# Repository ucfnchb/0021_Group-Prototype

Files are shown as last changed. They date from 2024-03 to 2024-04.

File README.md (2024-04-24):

# Coastal Echoes 
## Introduction
Coastal Echoes is an innovative project combining real-time environmental data with interactive visualization techniques to present dynamic coastal scenes. It utilizes real-time tidal and wind data to animate coastal landscapes visually, allowing the physical reproduction of natural phenomena such as wave motion and beach coverage. This project serves as both a functional tool for marine enthusiasts and an artistic decoration.


## Project Goals
The main objective of Coastal Echoes is to integrate real-time environmental data with Internet of Things technology to generate dynamic representations of coastal environments, helping target users such as shell collectors, surfers, and beachgoers understand and visualize tidal and wind impacts in real-time.



## Product Video: https://www.youtube.com/watch?v=u9kxgSY_1j8
For more Information please see uploaded Powerpoint Presentations.
## Features
* Real-Time Data Visualization: Using tide and wind data to illustrate their effects on wave motion and beach coverage.
* Physical Prototype: Features a motorized mechanism that simulates ocean wave movements correlated with real-time wind speed data.
* LED Visualization: An LED strip displays tide levels with color gradients, enhancing visual feedback.
* User-Friendly Interface: Designed to be intuitive and accessible for all user types.
## Getting Started
### Prerequisites
* Before starting with the installation of the Coastal Echoes project, ensure that you have the following:
* Access to the internet and a suitable environment to run Python scripts (e.g., Google Colab, Jupyter Notebook, or a local Python environment).
* Two APIs for real-time environmental data:
* Wind speed API
* Tide value API
* MQTT broker setup to publish and subscribe to topics.
* Arduino IDE installed on your computer for programming the Arduino Uno WiFi Rev2.
* The following libraries installed in your Arduino IDE:
* MQTT for handling MQTT connections.
* Servo to control the servo motors.
* WiFiNINA for network connectivity on Arduino.
* A Prusa 3D printer or access to one for printing the required parts.
* The 3D model source files for printing parts, available in the GitHub repository.
## Installation
### Software Setup
1.Clone the repository to your local machine or development environment:
```bash
git clone https://github.com/ucfnchb/0021_Group-Prototype.git
```
2.Navigate to the cloned directory and locate the Python scripts for retrieving data from the environmental APIs. These scripts are designed to publish data to MQTT topics. Run these scripts in your chosen environment (local or cloud-based).<br>
3.Locate the Arduino Code folder in the repository, which contains the scripts for the Arduino. You will upload these scripts to the Arduino board in later steps.
### Hardware Assembly

1.Print the required 3D parts using the model source files provided in the repository's 3D_Models folder.Laser cut from the wave dxf file<br>
2.Assemble the hardware according to the assembly diagrams and instructions found in the Diagrams folder. This includes fitting together the 3D-printed parts and the electronic components.<br>
3.Install the LED strips, servo motors, and the Arduino Uno WiFi Rev2 on the assembled hardware.



4. Material for enclosure provided below: 3mm Acrylic board, clear Acetate sheets, Florescent Paint.



### Arduino Configuration
1.Open the Arduino IDE and install the necessary libraries (MQTT, Servo, and WiFiNINA) via the Library Manager. <br>
2.Open the Arduino scripts provided in the Arduino Code folder. <br>
3.Configure the scripts with the correct MQTT topics that the Python scripts are publishing to.<br>
https://github.com/ucfnchb/0021_Group-Prototype/tree/main/API<br>
4.Upload the scripts to your Arduino board, ensuring that it's connected to your computer via USB.<br>
https://github.com/ucfnchb/0021_Group-Prototype/tree/main/Arduino%20Code<br>
5.Connect the Arduino to the local Wi-Fi network as instructed in the script comments.<br>
6.Once the setup is complete, the Arduino board should start receiving data from MQTT and controlling the LED strips and servo motors accordingly, reflecting the real-time environmental data in the physical prototype.
### Usage
* USB Power
* Connect the device to a WiFi network.
* The device will automatically start receiving data and simulating the environmental conditions of the NewHeaven coast.
## Prototype Design
The design process involved meticulous planning and execution, focusing on creating a responsive visualization that is both accurate and pleasing to the eye. For detailed design descriptions, Please see attached DesignDocs. 
## Future Work
Future enhancements will focus on integrating predictive features to forecast unfavorable tidal and wind conditions. We are also exploring options to enhance the device's durability and functionality over prolonged use.
## Contact
Project manager: Stella Chen yanjun.chen.23@ucl.ac.uk

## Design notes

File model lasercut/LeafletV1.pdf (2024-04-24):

# Coastal Echoes

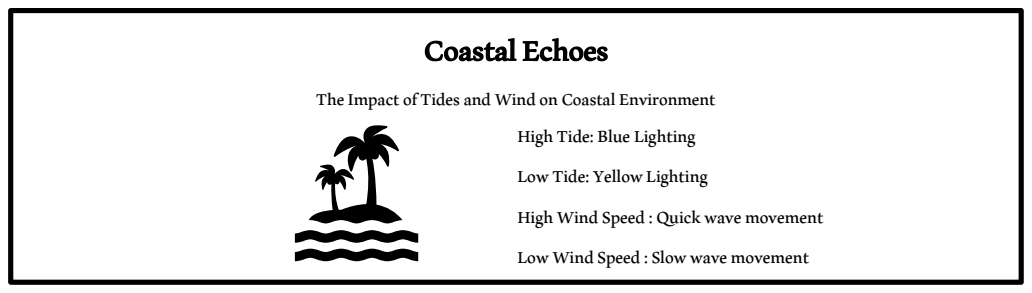
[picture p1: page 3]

The Impact of Tides and Wind on Coastal Environment

High Tide: Blue Lighting
Low Tide: Yellow Lighting
High Wind Speed : Quick wave movement
Low Wind Speed : Slow wave movement

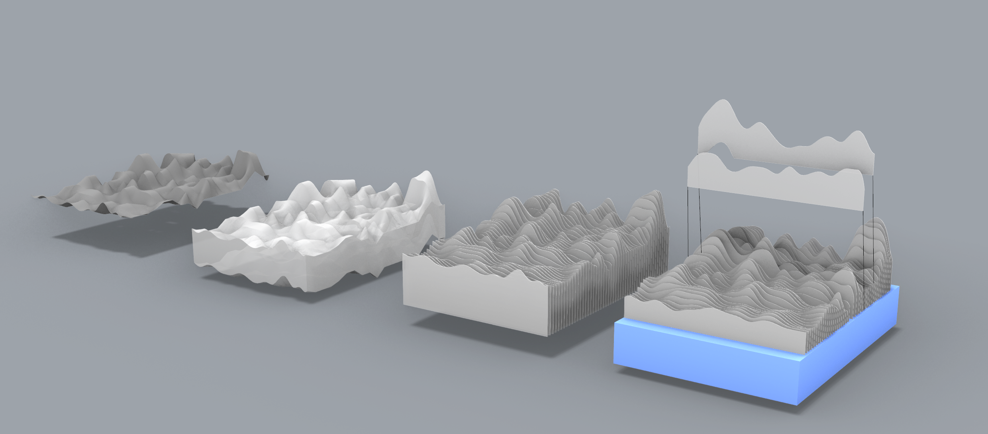
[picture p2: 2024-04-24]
model lasercut/model Image/屏幕截图 2024-03-17 190605.png

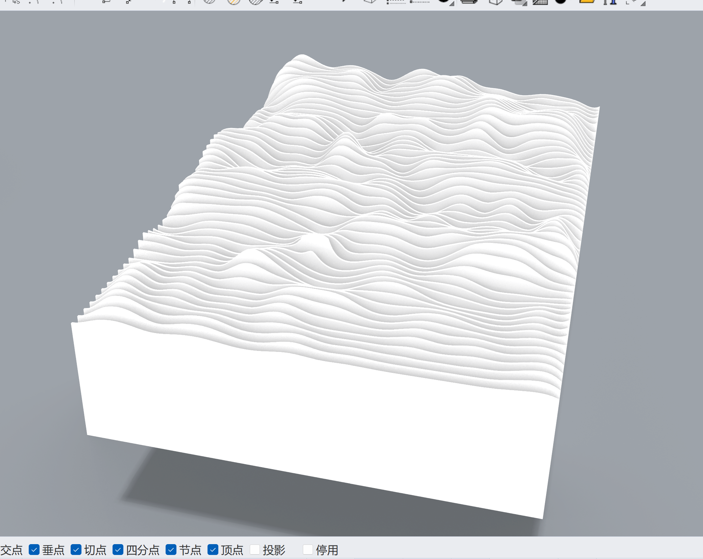
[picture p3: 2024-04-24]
model lasercut/model Image/屏幕截图 2024-02-27 165443.png

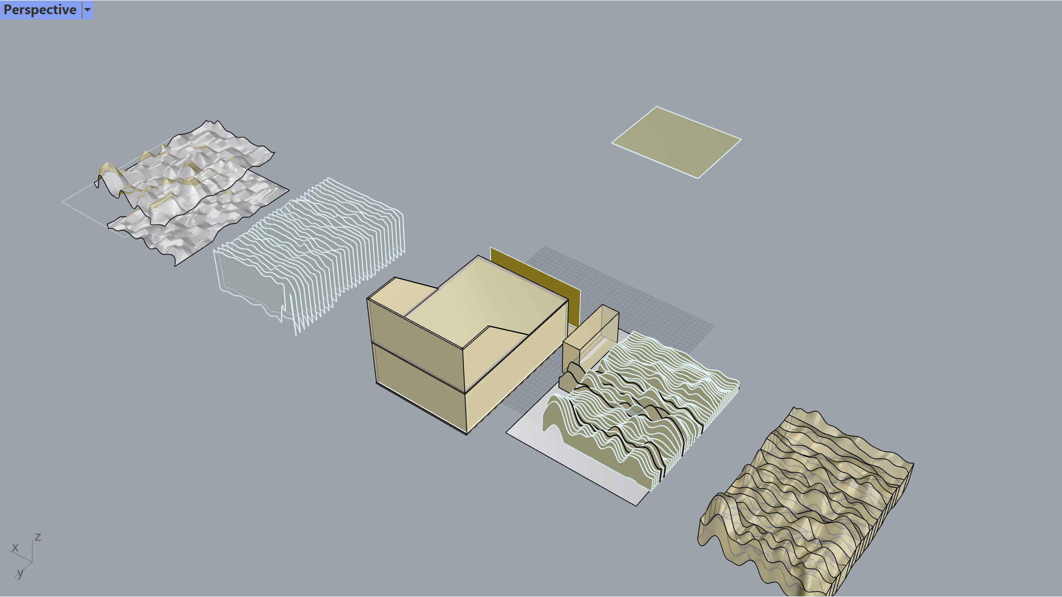
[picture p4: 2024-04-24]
model lasercut/model Image/屏幕截图 2024-02-27 154011.png

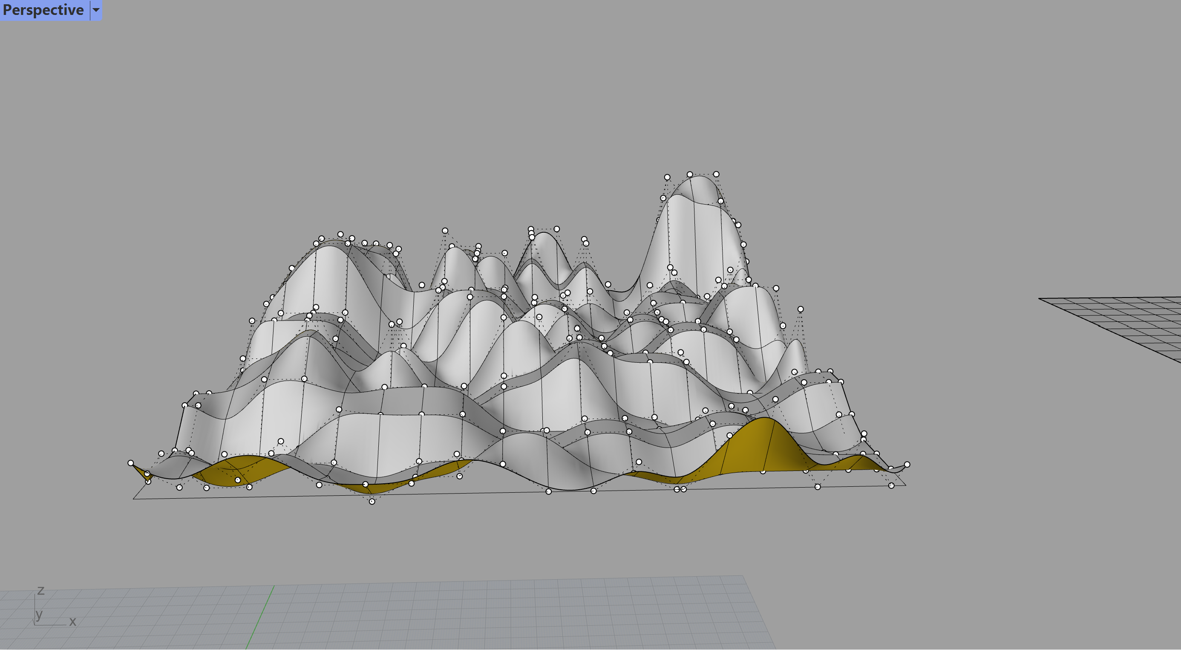
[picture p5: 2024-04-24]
model lasercut/model Image/屏幕截图 2024-02-25 125445.png

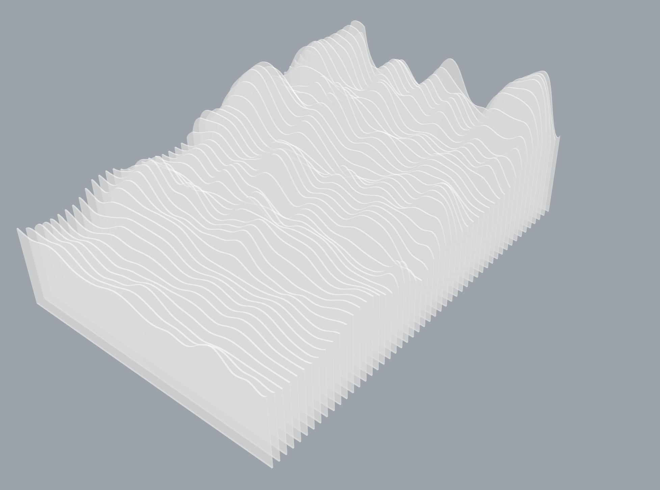
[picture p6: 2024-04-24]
model lasercut/model Image/屏幕截图 2024-03-17 184851.png

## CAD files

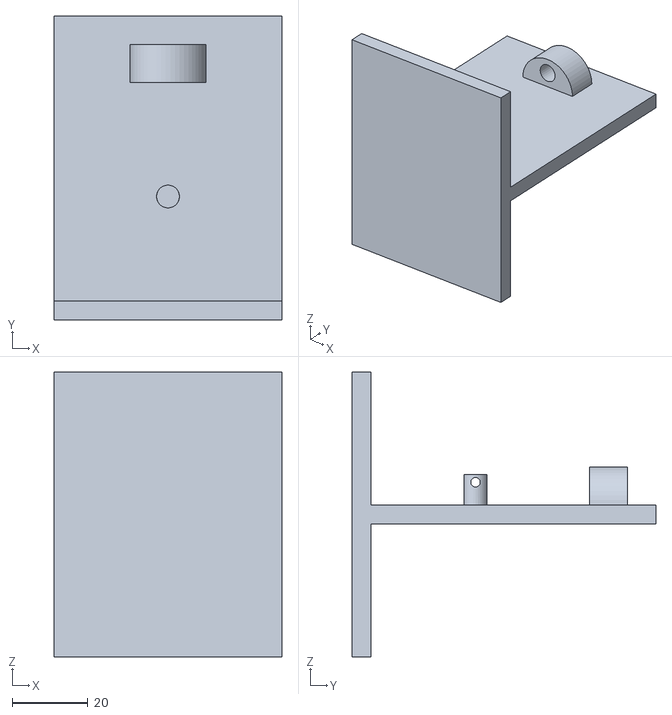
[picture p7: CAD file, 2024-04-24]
3D printing/foundation 4.stl
60.0 x 80.0 x 75.0

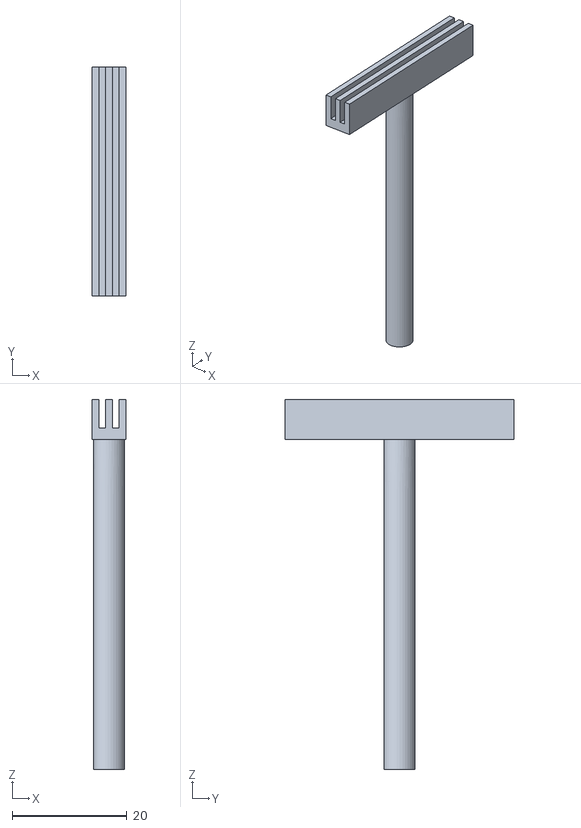
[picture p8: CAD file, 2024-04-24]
model lasercut/paper clicker.stl
5.94 x 40.0 x 64.5

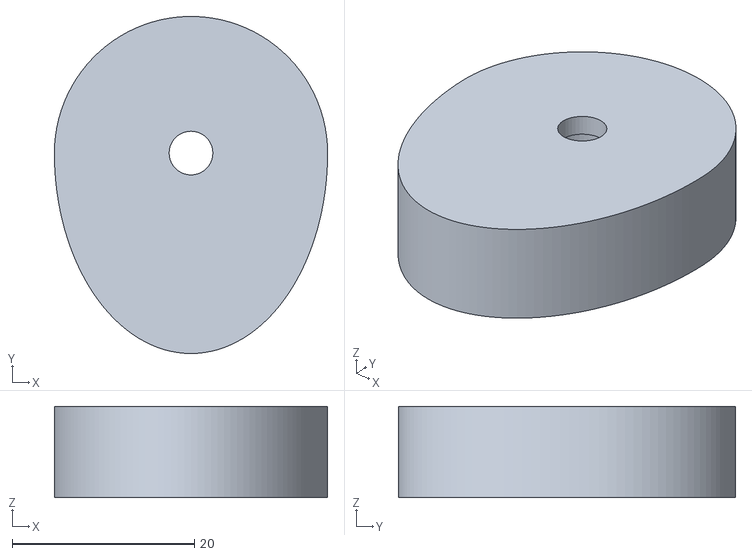
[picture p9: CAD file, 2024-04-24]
3D printing/smalleggshape.stl
30.0 x 37.0 x 10.0

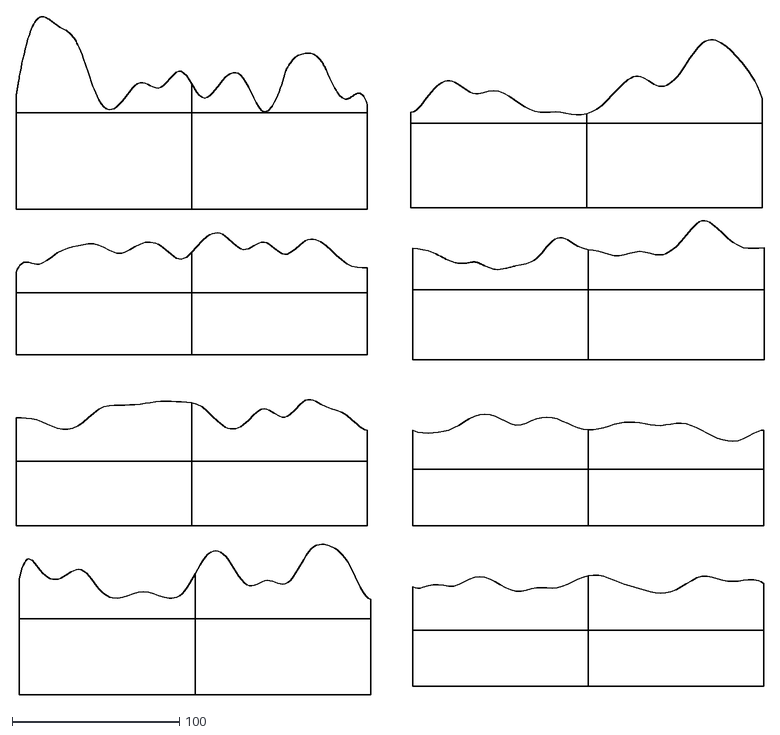
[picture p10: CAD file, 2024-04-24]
model lasercut/8 waves acrylic lasercut.dxf
447.0 x 405.2

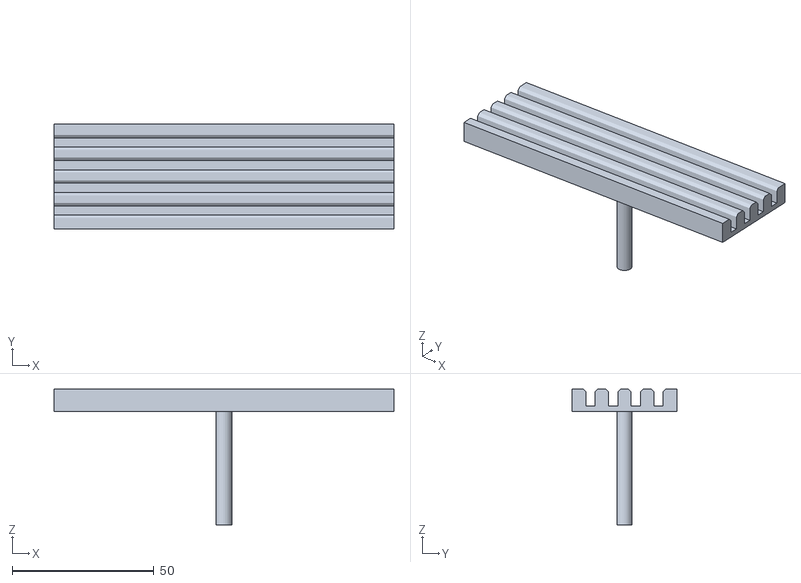
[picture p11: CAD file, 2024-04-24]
3D printing/final version of arcylic cliper.stl
120.0 x 37.0 x 48.0

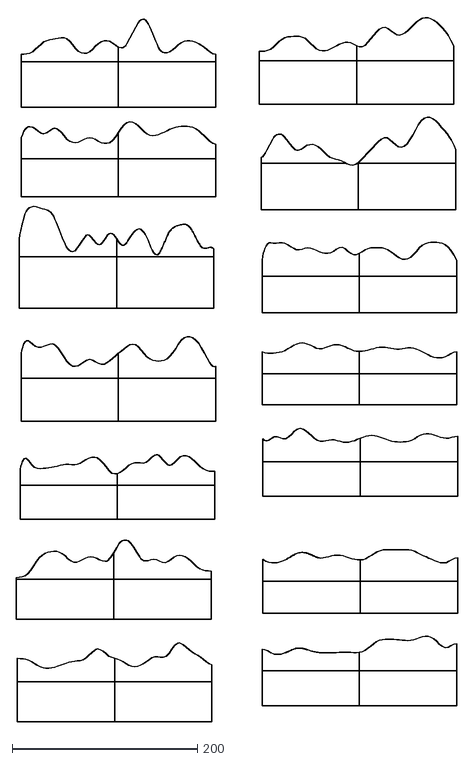
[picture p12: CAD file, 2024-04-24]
model lasercut/wave 14 pieces.dxf
476.0 x 760.8

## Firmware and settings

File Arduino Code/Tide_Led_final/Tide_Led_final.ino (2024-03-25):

#include <WiFiNINA.h>
#include <PubSubClient.h>
#include <Adafruit_NeoPixel.h>

// WiFi credentials
const char* ssid = "xxxxxx";
const char* password = "xxxxxx";

// MQTT Broker settings
const char* mqtt_server = "mqtt.cetools.org";
int mqtt_port = 1884;
const char* mqtt_user = "student";
const char* mqtt_password = "xxxxxx";

WiFiClient wifiClient;
PubSubClient client(wifiClient);

#define LED_PIN    7 // Adjust to the pin connected to your LED strip
#define NUMPIXELS 60  // Adjust to the number of pixels in your LED strip
Adafruit_NeoPixel strip(NUMPIXELS, LED_PIN, NEO_GRB + NEO_KHZ800);

float lastTideData = -99999; // Use a clearly out-of-range initial value to ensure first comparison triggers change
bool wasPositive = true; // Track the sign of the last tide data
bool wasHighTide = false; // Track if the last tide data was >= 2

void setup() {
  Serial.begin(9600);
  setupWiFiAndMQTT();
  strip.begin();
  strip.show();  // Turn all LEDs off ASAP
}

void loop() {
  if (!client.connected()) {
    reconnect();
  }
  client.loop();
  // Continuously check for high tide condition to trigger gentle flashing
  if (wasHighTide) {
    gentleFlash();
  }
}

void setupWiFiAndMQTT() {
  Serial.print("Connecting to ");
  Serial.println(ssid);
  WiFi.begin(ssid, password);
  while (WiFi.status() != WL_CONNECTED) {
    delay(500);
    Serial.print(".");
  }
  Serial.println("WiFi connected");
  Serial.println("IP address: ");
  Serial.println(WiFi.localIP());

  client.setServer(mqtt_server, mqtt_port);
  client.setCallback(callback);
  reconnect();
}

void reconnect() {
  while (!client.connected()) {
    Serial.print("Attempting MQTT connection...");
    if (client.connect("arduinoClient", mqtt_user, mqtt_password)) {
      Serial.println("connected");
      client.subscribe("student/ucfnhy0/tide");
    } else {
      Serial.print("failed, rc=");
      Serial.print(client.state());
      Serial.println(" try again in 5 seconds");
      delay(5000);
    }
  }
}

void callback(char* topic, byte* payload, unsigned int length) {
  Serial.print("Message arrived [");
  Serial.print(topic);
  Serial.print("] ");

  String message;
  for (int i = 0; i < length; i++) {
    message += (char)payload[i];
  }
  Serial.println(message);

  float tideData = message.toFloat();

  // Handle high tide condition separately
  if (tideData >= 2) {
    wasHighTide = true; // Enable gentle flashing in the loop()
    return; // Skip further processing to keep flashing
  } else {
    // If transitioning from high tide to lower tide
    if (wasHighTide) {
      if (tideData > 0) {
        gradualChange(255, 220, 0, 0, 0, 255); // From yellow to blue for positive tide
      } else {
        gradualChange(0, 0, 255, 255, 220, 0); // From blue to yellow for negative tide
      }
    } else {
      // Standard tide change handling when not previously in a high tide condition
      bool isPositive = tideData > 0;
      if (isPositive != wasPositive) { // If the sign has changed
        if (isPositive) { // Changed from negative to positive
          gradualChange(255, 220, 0, 0, 0, 255); // From blue to yellow
        } else { // Changed from positive to negative
          gradualChange(0, 0, 255, 255, 220, 0); // From yellow to blue
        }
      }
    }
    // Update tracking variables
    lastTideData = tideData;
    wasPositive = tideData > 0;
    wasHighTide = tideData >= 2;
  }
}

void setColor(int red, int green, int blue) {
  for(int i = 0; i < strip.numPixels(); i++) {
    strip.setPixelColor(i, strip.Color(red, green, blue));
  }
  strip.show();
}

void gradualChange(int startRed, int startGreen, int startBlue, int endRed, int endGreen, int endBlue) {
  int steps = 50; // Number of steps in the transition
  int duration = 5000; // Total duration of the change in milliseconds
  int delayTime = duration / steps; // Time to wait between updates

  for (int i = 0; i <= steps; i++) {
    float ratio = (float)i / (float)steps;
    int red = startRed + ratio * (endRed - startRed);
    int green = startGreen + ratio * (endGreen - startGreen);
    int blue = startBlue + ratio * (endBlue - startBlue);
    setColor(red, green, blue);
    delay(delayTime);
  }
}

void gentleFlash() {
  // Implement gentle blue flashing effect
  setColor(0, 0, 255); // Blue color
  delay(300); // On for 300 ms
  strip.clear(); // Turn off
  strip.show();
  delay(300); // Off for 300 ms
}

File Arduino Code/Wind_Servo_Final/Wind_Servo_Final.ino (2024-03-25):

#include <Servo.h>
#include <WiFiNINA.h>
#include <PubSubClient.h>

Servo myservo;  // Servo object to control a servo
Servo servo2;   // Second servo object
Servo servo3;   // Third servo object
Servo servo4;   // Fourth servo object, labeled as servo4

// WiFi credentials
const char* ssid = "xxxxxx";
const char* password = "xxxxxxx";

// MQTT Broker settings
const char* mqtt_server = "mqtt.cetools.org";
int mqtt_port = 1884;
const char* mqtt_user = "student";
const char* mqtt_password = "xxxxxx";

WiFiClient wifiClient;
PubSubClient client(wifiClient);

void callback(char* topic, byte* payload, unsigned int length) {
  Serial.print("Message arrived [");
  Serial.print(topic);
  Serial.print("] ");

  String message;
  for (int i = 0; i < length; i++) {
    message += (char)payload[i];
  }
  Serial.println(message);

  int speed = message.toInt();
  controlServo(speed);
}

void controlServo(int speed) {
  int pulseWidth = map(speed, 0, 75, 90, 180);
  myservo.write(pulseWidth);  // Control the first servo
  servo2.write(pulseWidth);   // Control the second servo similarly
  servo3.write(pulseWidth);   // Control the third servo similarly
  servo4.write(pulseWidth);   // Control the fourth servo similarly
}

void setup() {
  Serial.begin(9600);
  myservo.attach(11); // Attach the first servo on pin 11
  servo2.attach(10);  // Attach the second servo on pin 10
  servo3.attach(9);   // Attach the third servo on pin 9
  servo4.attach(8);   // Attach the fourth servo on pin 8
  
  setupWiFiAndMQTT();
}

void loop() {
  if (!client.connected()) {
    reconnect();
  }
  client.loop();
}

void setupWiFiAndMQTT() {
  Serial.print("Connecting to ");
  Serial.println(ssid);
  WiFi.begin(ssid, password);
  while (WiFi.status() != WL_CONNECTED) {
    delay(500);
    Serial.print(".");
  }
  Serial.println("WiFi connected");
  Serial.println("IP address: ");
  Serial.println(WiFi.localIP());

  client.setServer(mqtt_server, mqtt_port);
  client.setCallback(callback);
  reconnect();
}

void reconnect() {
  while (!client.connected()) {
    Serial.print("Attempting MQTT connection...");
    if (client.connect("arduinoClient", mqtt_user, mqtt_password)) {
      Serial.println("connected");
      client.subscribe("student/ucfnhy0/wind"); // Ensure this topic is correct for your data
    } else {
      Serial.print("failed, rc=");
      Serial.print(client.state());
      Serial.println(" try again in 5 seconds");
      delay(5000);
    }
  }
}

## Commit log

2024-03-04 使用 Colaboratory 创建
2024-03-04 Led Strip testing code
2024-03-25 Final code of the tide and led function
2024-03-25 Final code of wind and servo function
2024-03-25 Create Arduino Code
2024-03-25 Final Led coding file
2024-03-25 final tide and led function file
2024-04-24 Add Model dxf file and images
    [8 waves acrylic lasercut.dxf, paper clicker.stl, wave 14 pieces.dxf]
2024-04-24 Arduino Code
